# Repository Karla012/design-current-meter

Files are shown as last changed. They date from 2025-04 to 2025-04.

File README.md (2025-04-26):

# Diseño de un Sistema de Medición de Corriente para Microcontroladores con Transmisión Inalámbrica

### Autores
- **Karla Vanessa Ruíz González** — Universidad Industrial de Santander  
- **Óscar Andrés Meza Ortiz** — Universidad Industrial de Santander  

---

## Descripción del Proyecto

Este proyecto tiene como objetivo el diseño de un sistema electrónico operado por batería, que permita medir la corriente de operación de un microcontrolador en sus distintos modos de funcionamiento: modo normal y modo de sueño profundo. La medición se realiza de forma periódica, alternando entre ambos modos, lo que permite analizar el comportamiento energético del microcontrolador a lo largo del tiempo.

El sistema está diseñado para ofrecer precisión y bajo burden voltage en la medición, permitiendo detectar corrientes tanto en el orden de los miliamperios como de los microamperios. Para ello, se implementa un sistema de cambio de rango (manual o automático) que adapta la medición al nivel de corriente detectado. La señal medida es amplificada y enviada a un conversor analógico-digital, y finalmente, los datos se transmiten inalámbricamente a través de un microcontrolador ESP32.

---

## Estructura del Repositorio

- `docs/` – Informe final y presentación del proyecto.
- `hardware/` – Esquemáticos y diseño de PCB del circuito.
- `firmware/` – Código del microcontrolador para la transmisión inalámbrica.
- `simulacion/` – Resultados y archivos de simulaciones.
- `app_inventor/` – Archivos del diseño de la app móvil para visualizar los datos.

---

## Transmisión de Datos

El sistema emplea un ESP32 para la transmisión inalámbrica de las mediciones. Estas son recibidas por una aplicación desarrollada en [App Inventor](https://appinventor.mit.edu/), permitiendo visualizar en tiempo real el comportamiento de la corriente en el microcontrolador evaluado.

---

## Estado del Proyecto

Este trabajo corresponde al diseño completo y simulado del sistema de medición. No se realizó una implementación física, pero se desarrollaron y documentaron todos los bloques funcionales, respaldados por simulaciones, selección de componentes y diseño de una aplicación móvil funcional.

---

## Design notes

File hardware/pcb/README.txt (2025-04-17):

Contiene los archivos del diseño de la PCB para fabricación.

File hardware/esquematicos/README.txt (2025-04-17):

Contiene los esquemáticos del circuito de medición de corriente.

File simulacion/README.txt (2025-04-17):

Contiene resultados de simulaciones del sistema de medición.

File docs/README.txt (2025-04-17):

Contiene el informe y la presentación final del proyecto.

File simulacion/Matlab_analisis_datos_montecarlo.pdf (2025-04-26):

% Cargar los datos del archivo
fileID = fopen('Datos_montecarlo.txt', 'r');

% Inicializar un arreglo para almacenar los valores de V(n005) V = [];

% Leer el archivo línea por línea
tline = fgetl(fileID);
while ischar(tline)
% Verificar si la línea contiene un valor de V(n005) (con formato numérico)
if ~isempty(regexp(tline, '^[+-]?\d*\.?\d+', 'once'))
% Extraer el valor de V(n005) de la línea
values = sscanf(tline, '%e');
V = [V; values(2)]; % Solo tomar el segundo valor (V(n005)) end
tline = fgetl(fileID);
end

% Cerrar el archivo
fclose(fileID);

% Verificar los primeros valores extraídos disp('Primeros 10 valores de Vout:');

Primeros 10 valores de Vout:

disp(V(1:10));

1.0016
1.0016
1.0016
0.9843
0.9843
0.9843
1.0009
1.0009
1.0009
0.9948

% Simulación de Monte Carlo
num_simulations = 1000; % Número de simulaciones simulated_values = zeros(num_simulations, length(V));

% Realizar las simulaciones con variabilidad aleatoria
for i = 1:num_simulations
% Agregar ruido aleatorio a los valores de V
noise = 0.01 * randn(size(V)); % Generar ruido aleatorio simulated_values(i, :) = V + noise; % Simular con ruido añadido end

% Graficar el histograma de la distribución de los valores simulados

figure;
histogram(simulated_values(:), 20, 'Normalization', 'pdf', 'FaceColor', 'b'); % Histograma con 50 bins
hold on;

% Ajuste de una distribución normal a los datos simulados
mu = mean(simulated_values(:)); % Media de los datos simulados
sigma = std(simulated_values(:)); % Desviación estándar de los datos simulados
x = linspace(min(simulated_values(:)), max(simulated_values(:)), 100); % Rango para la función de densidad
y = normpdf(x, mu, sigma); % Calcular la función de densidad de probabilidad normal

% Graficar la línea roja
plot(x, y, 'r', 'LineWidth', 2); % Línea roja para la PDF ajustada

xlabel('Vout');
ylabel('Probability');
title('Monte Carlo y Ajuste normal (10 Ω)');
hold off;

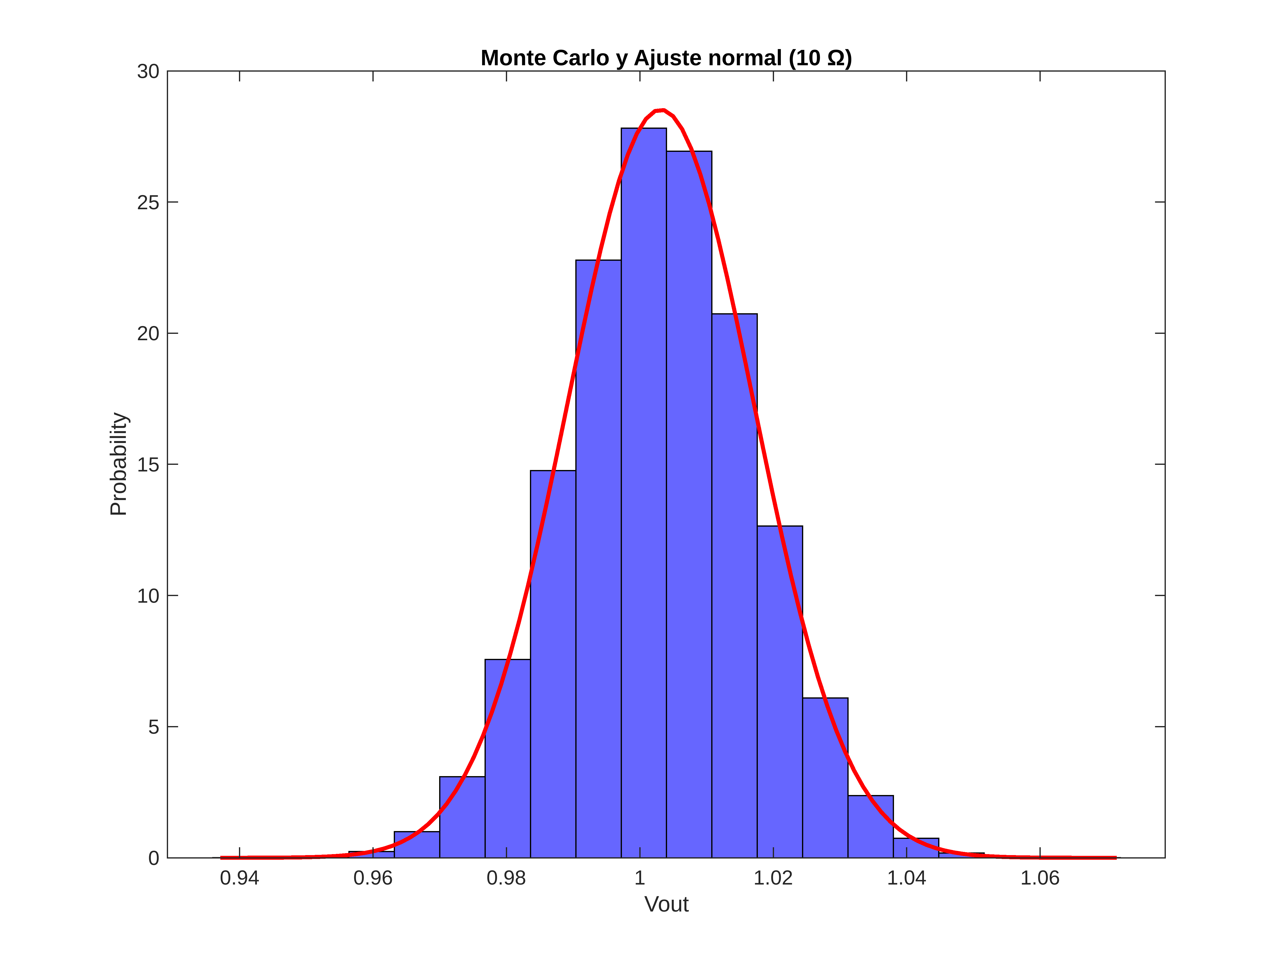
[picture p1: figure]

Montecarlo para resistencia de 0.01 Ω

% Cargar los datos del archivo
fileID = fopen('Datos_montecarlo0_01.txt', 'r');

% Inicializar un arreglo para almacenar los valores de V(n005) V = [];

% Leer el archivo línea por línea
tline = fgetl(fileID);
while ischar(tline)
% Verificar si la línea contiene un valor de V(n005) (con formato numérico)
if ~isempty(regexp(tline, '^[+-]?\d*\.?\d+', 'once'))
% Extraer el valor de V(n005) de la línea
values = sscanf(tline, '%e');
V = [V; values(2)]; % Solo tomar el segundo valor (V(n005)) end
tline = fgetl(fileID);
end

% Cerrar el archivo
fclose(fileID);

% Verificar los primeros valores extraídos disp('Primeros 10 valores de Vout:');

Primeros 10 valores de Vout:

disp(V(1:10));

1.0016
1.0016
1.0016
0.9843
0.9843
0.9843
1.0009
1.0009
1.0009
0.9948

% Simulación de Monte Carlo
num_simulations = 1000; % Número de simulaciones simulated_values = zeros(num_simulations, length(V));

% Realizar las simulaciones con variabilidad aleatoria
for i = 1:num_simulations
% Agregar ruido aleatorio a los valores de V
noise = 0.01 * randn(size(V)); % Generar ruido aleatorio simulated_values(i, :) = V + noise; % Simular con ruido añadido end

% Graficar el histograma de la distribución de los valores simulados

figure;
histogram(simulated_values(:), 20, 'Normalization', 'pdf', 'FaceColor', 'b'); % Histograma con 50 bins
hold on;

% Ajuste de una distribución normal a los datos simulados
mu = mean(simulated_values(:)); % Media de los datos simulados
sigma = std(simulated_values(:)); % Desviación estándar de los datos simulados
x = linspace(min(simulated_values(:)), max(simulated_values(:)), 100); % Rango para la función de densidad
y = normpdf(x, mu, sigma); % Calcular la función de densidad de probabilidad normal

% Graficar la línea roja
plot(x, y, 'r', 'LineWidth', 2); % Línea roja para la PDF ajustada

xlabel('Vout');
ylabel('Probability');
title('Monte Carlo y Ajuste normal (0.01 Ω)');
hold off;

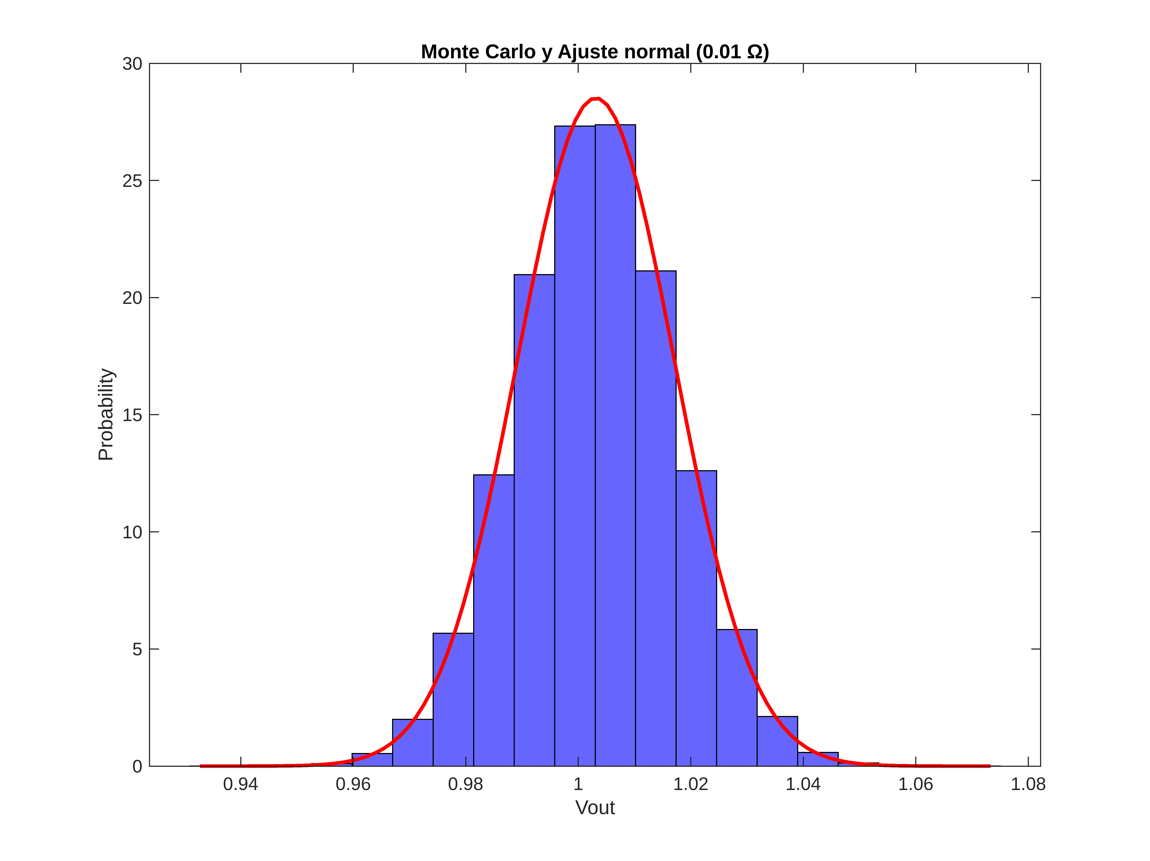
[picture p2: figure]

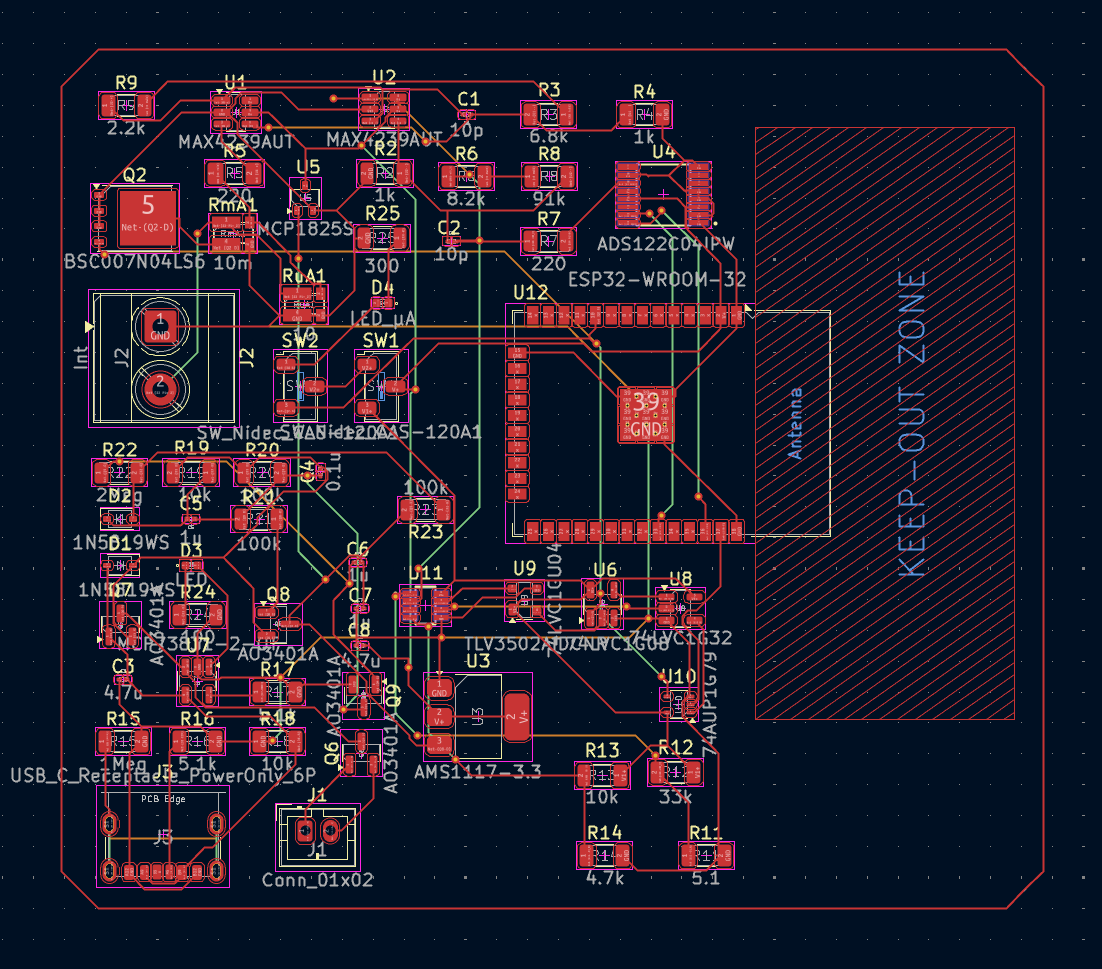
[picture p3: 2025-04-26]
hardware/pcb/Layout.png

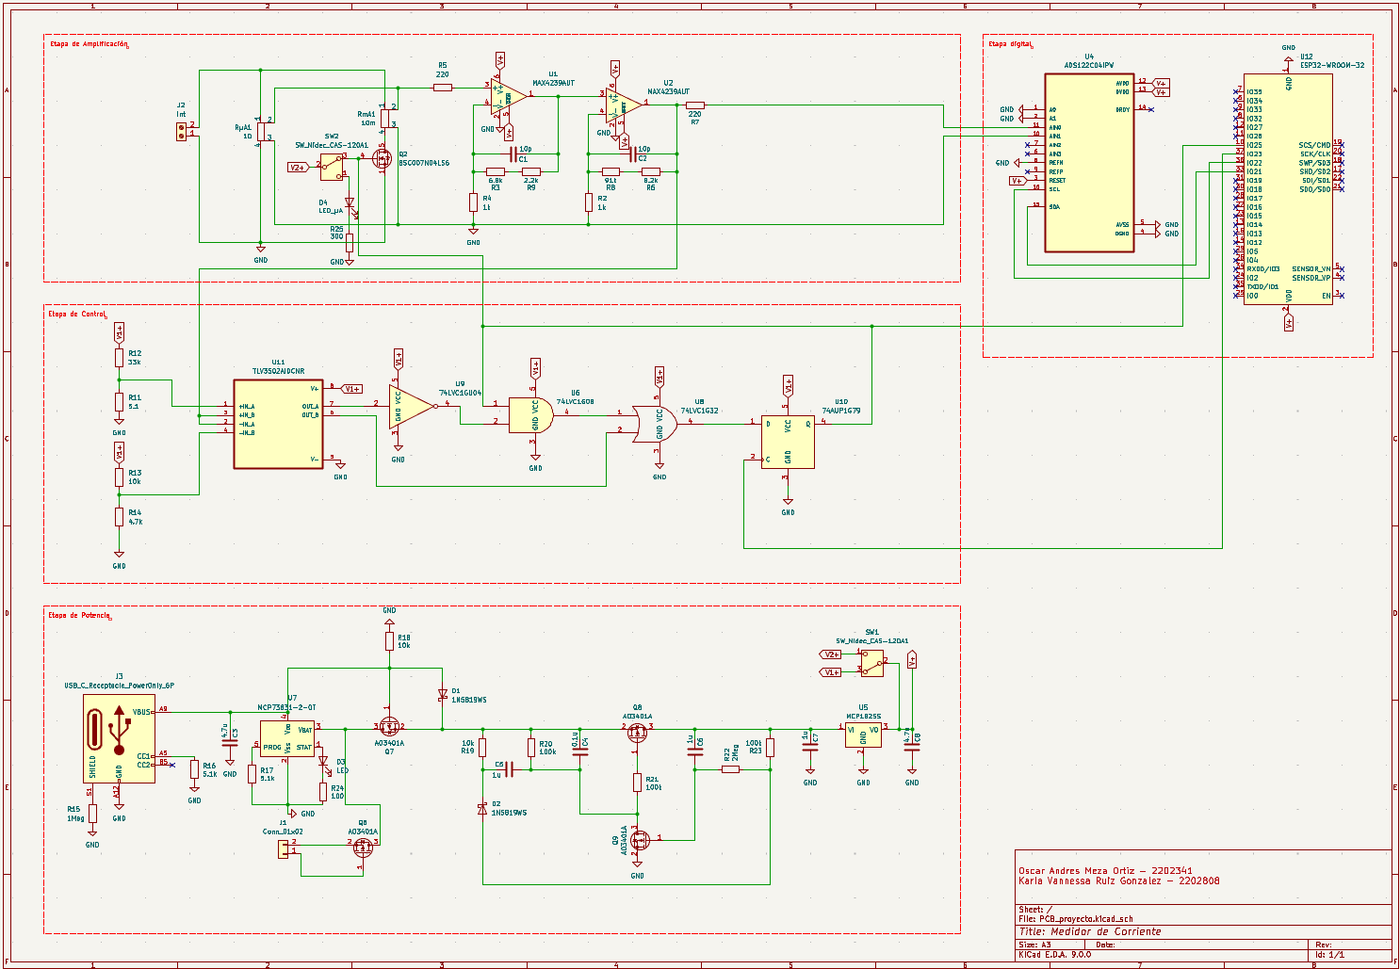
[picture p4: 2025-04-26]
hardware/esquematicos/Esquema_general.png

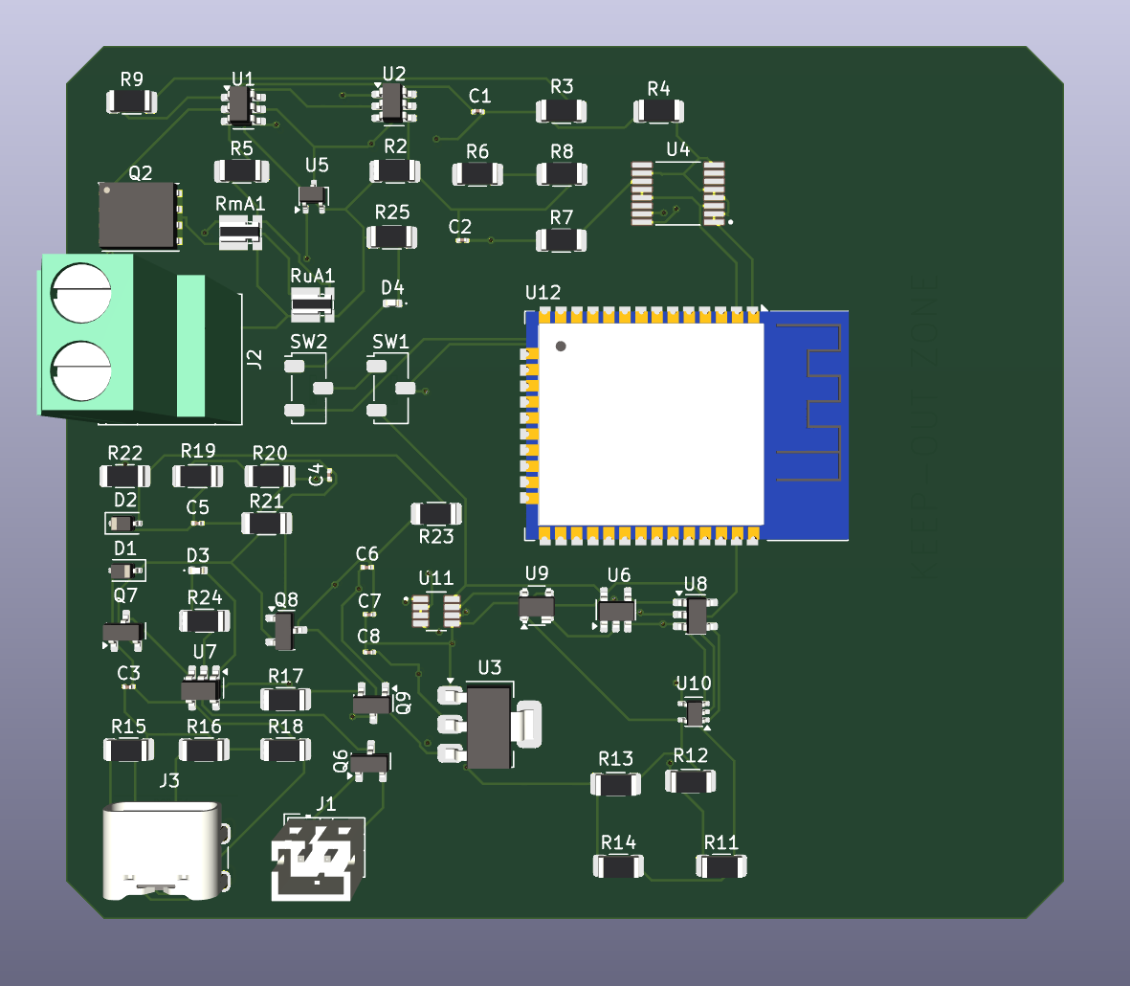
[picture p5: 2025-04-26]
hardware/pcb/PCB.png

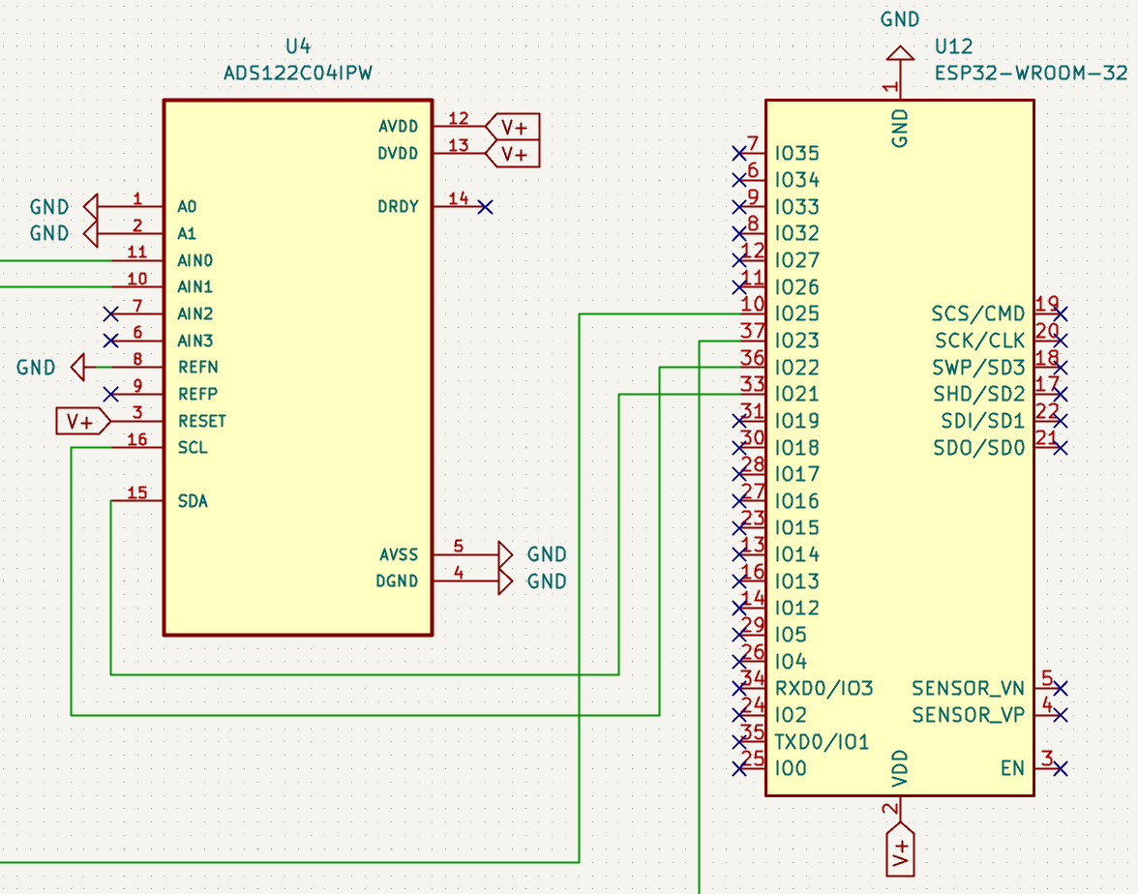
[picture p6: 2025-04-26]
hardware/esquematicos/E_Digital.png

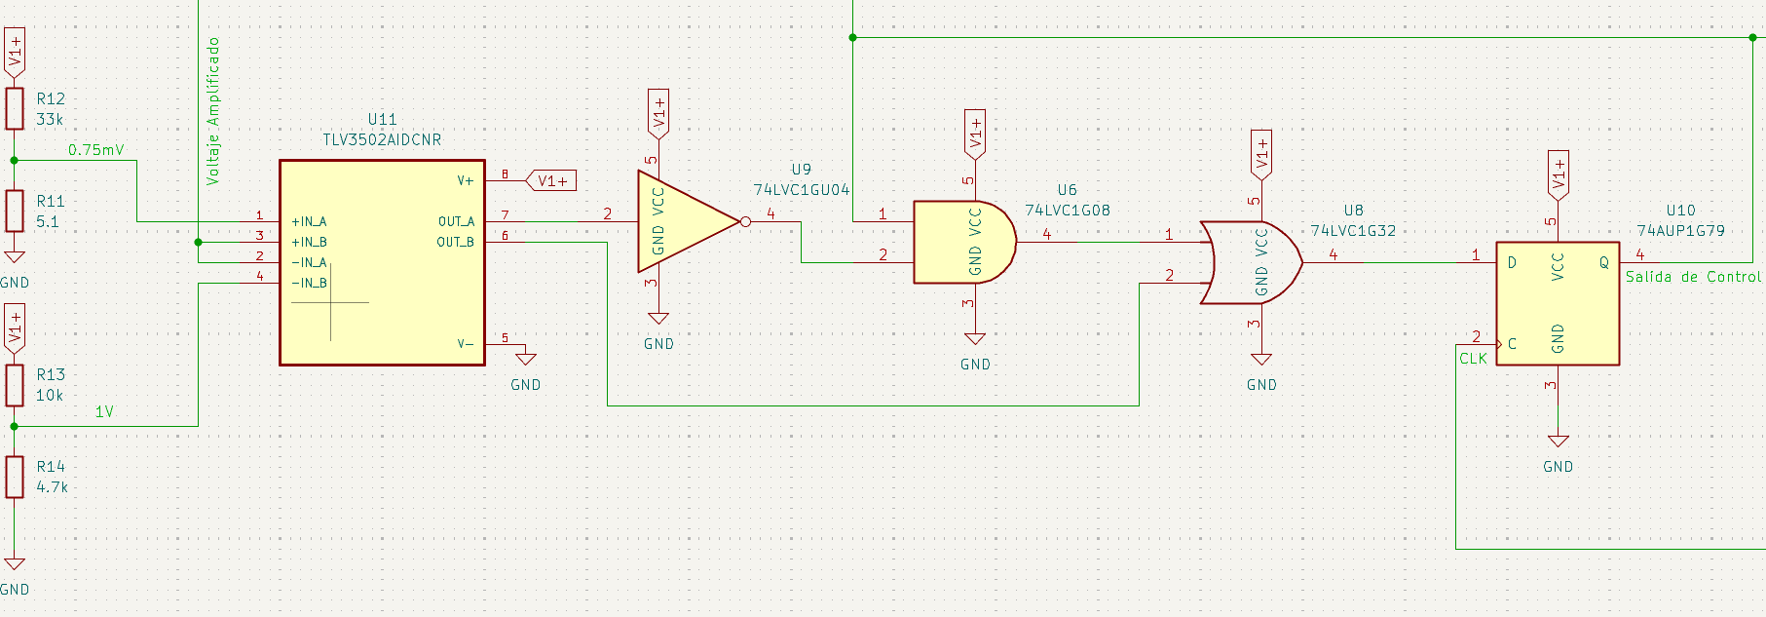
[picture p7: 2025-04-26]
hardware/esquematicos/E_control.png

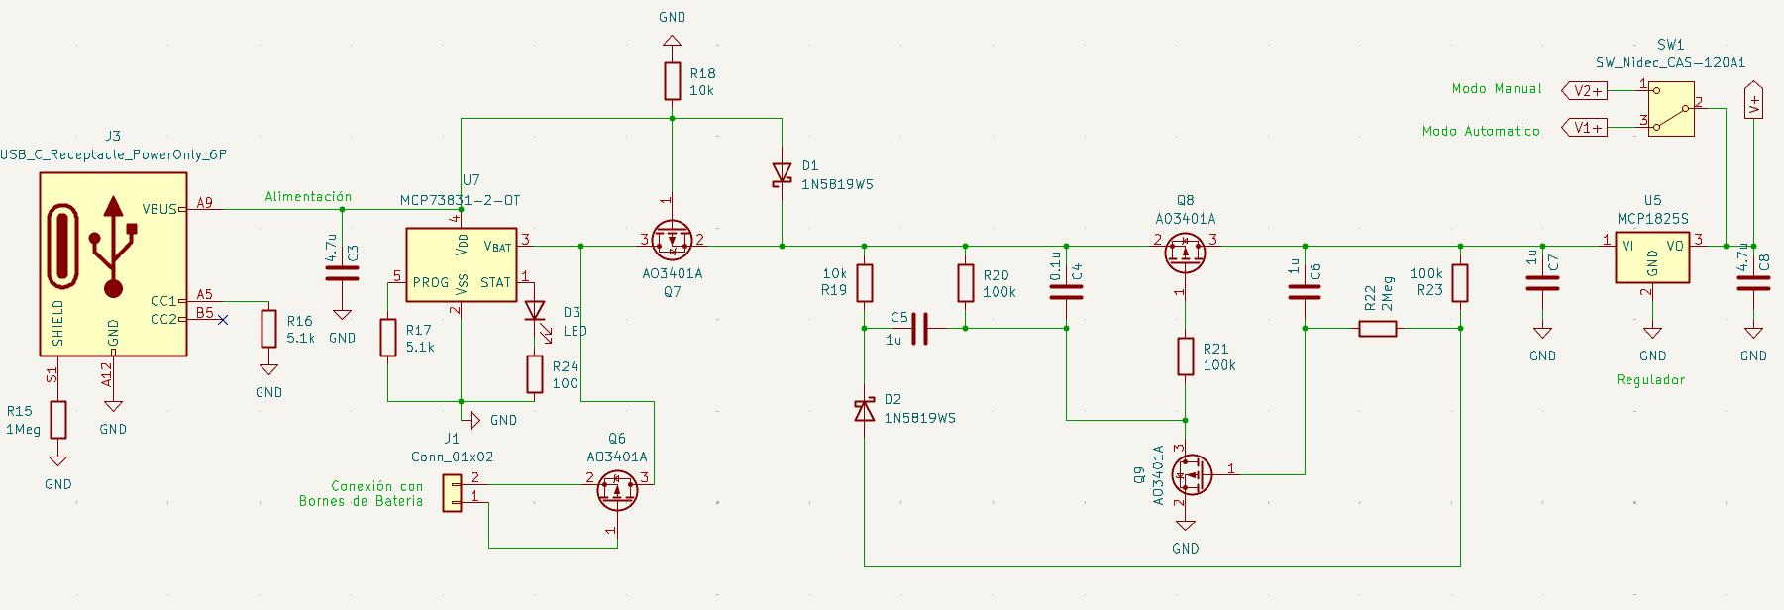
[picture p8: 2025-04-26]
hardware/esquematicos/Etapa_de_Potencia.png

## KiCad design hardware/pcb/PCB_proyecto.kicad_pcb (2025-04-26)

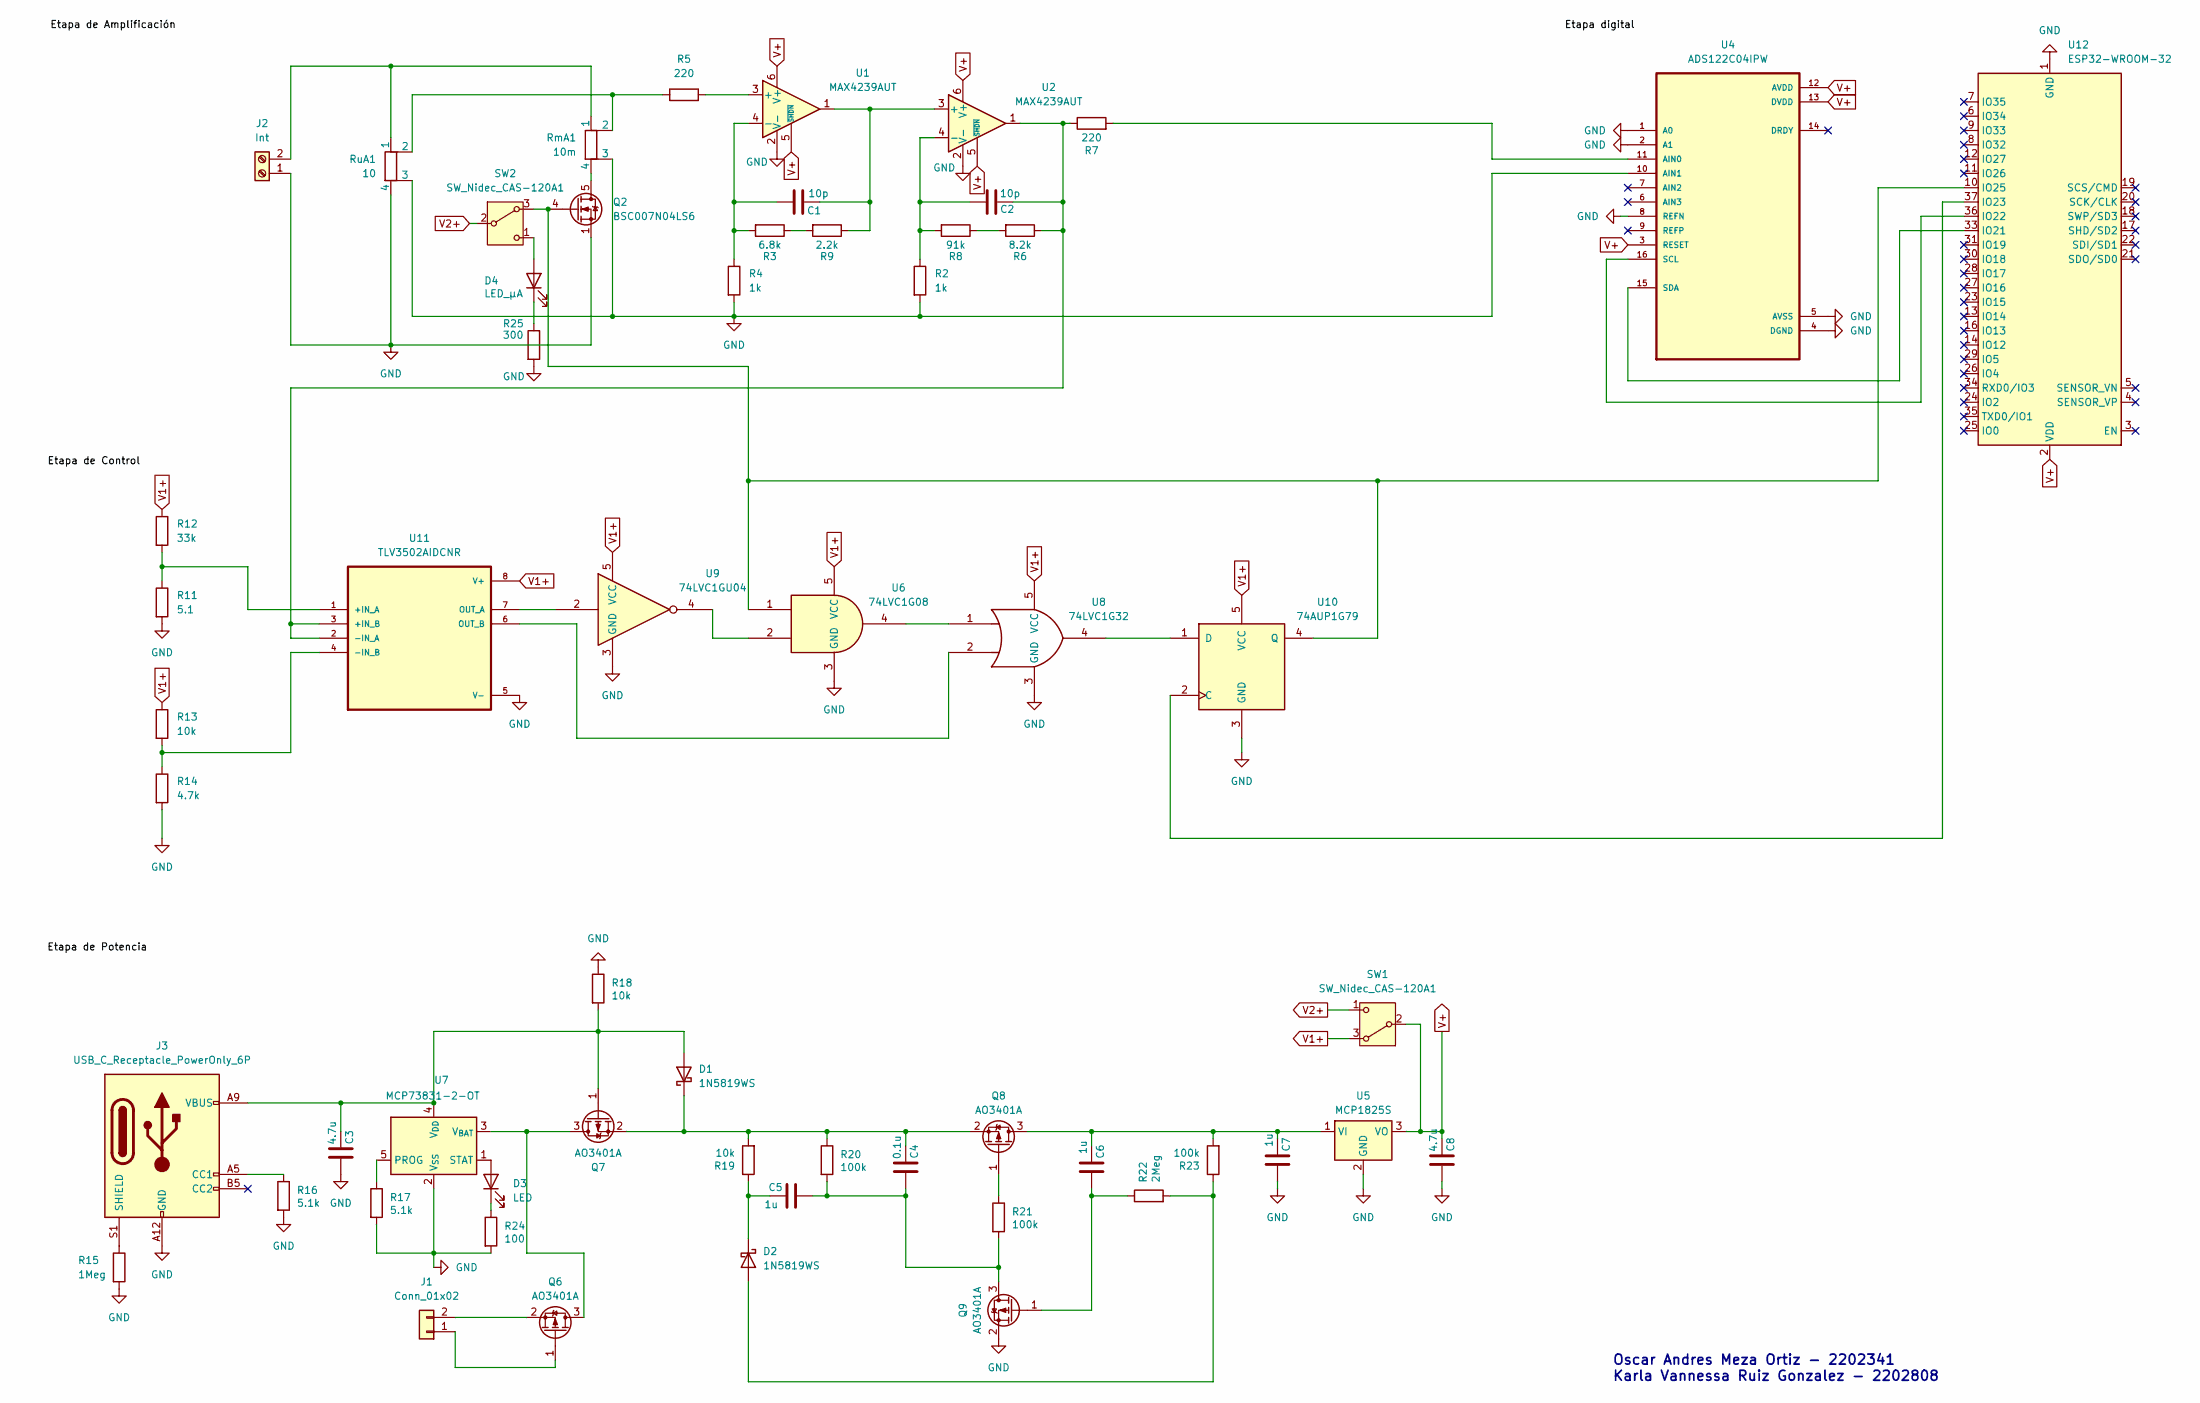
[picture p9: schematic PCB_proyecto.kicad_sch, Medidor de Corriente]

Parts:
C1, C2: 10p; C_0201_0603Metric
C3, C8: 4.7u; C_0201_0603Metric
C4: 0.1u; C_0201_0603Metric
C5, C6, C7: 1u; C_0201_0603Metric
D1, D2: 1N5819WS; D_SOD-323
D3: LED; LED_0402_1005Metric
D4: LED_µA; LED_0402_1005Metric
J1: Conn_01x02; JST_PH_B2B-PH-K_1x02_P2.00mm_Vertical
J2: Int; TerminalBlock_Phoenix_MKDS-3-2-5.08_1x02_P5.08mm_Horizontal
J3: USB_C_Receptacle_PowerOnly_6P; USB_C_Receptacle_GCT_USB4125-xx-x-0190_6P_TopMnt_Horizontal
Q2: BSC007N04LS6; TDSON-8-1
Q6, Q7, Q8, Q9: AO3401A; SOT-23
R2, R4: 1k; R_1206_3216Metric
R3: 6.8k; R_1206_3216Metric
R5: 220; R_1206_3216Metric_Pad1.30x1.75mm_HandSolder
R6: 8.2k; R_1206_3216Metric
R7: 220; R_1206_3216Metric
R8: 91k; R_1206_3216Metric
R9: 2.2k; R_1206_3216Metric
R11: 5.1; R_1206_3216Metric
R12: 33k; R_1206_3216Metric
R13, R18, R19: 10k; R_1206_3216Metric
R14: 4.7k; R_1206_3216Metric
R15: 1Meg; R_1206_3216Metric
R16, R17: 5.1k; R_1206_3216Metric
R20, R21, R23: 100k; R_1206_3216Metric
R22: 2Meg; R_1206_3216Metric
R24: 100; R_1206_3216Metric
R25: 300; R_1206_3216Metric
RmA1: 10m; R_Shunt_Vishay_WSKW0612
RuA1: 10; R_Shunt_Vishay_WSKW0612
SW1, SW2: SW_Nidec_CAS-120A1; Nidec_Copal_CAS-120A
U1, U2: MAX4239AUT; SOT-23-6
U4: ADS122C04IPW; SOP65P640X120-16N
U5: MCP1825S; SOT-323_SC-70
U6: 74LVC1G08; SOT-23-5
U7: MCP73831-2-OT; SOT-23-5
U8: 74LVC1G32; SOT-23-5
U9: 74LVC1GU04; SOT-143R
U10: 74AUP1G79; SOT-353_SC-70-5
U11: TLV3502AIDCNR; SOT65P280X145-8N
U12: ESP32-WROOM-32

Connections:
GND: C3.1, C7.1, C8.1, J2.1, J3.A12 (GND), J3.B12 (GND), Q2.1 (S), Q2.2 (S), Q2.3 (S), Q9.2 (S), R2.2, R4.2, R11.2, R14.2, R15.2, R16.2, R17.2, R18.1, R24.2, R25.2, RmA1.3, RuA1.3, RuA1.4, U1.2 (V-), U2.2 (V-), U4.1 (A0), U4.2 (A1), U4.4 (DGND), U4.5 (AVSS), U4.8 (REFN), U4.10 (AIN1), U5.2 (GND), U6.3 (GND), U7.2 (V_{SS}), U8.3 (GND), U9.3 (GND), U10.3 (GND), U11.5 (V-), U12.1 (GND), U12.15 (GND), U12.38 (GND), U12.39 (GND); also elsewhere on the board
unnamed: C3.2, D1.2 (A), J3.A9 (VBUS), J3.B9 (VBUS), Q7.1 (G), R18.2, U7.4 (V_{DD})
unnamed: C4.2, D1.1 (K), Q7.2 (S), Q8.2 (S), R19.2, R20.1
unnamed: D2.2 (A), R22.2, R23.1
unnamed: C5.2, D2.1 (K), R19.1
unnamed: D3.2 (A), U7.1 (STAT)
unnamed: D3.1 (K), R24.1
unnamed: D4.2 (A), SW2.1 (C)
unnamed: D4.1 (K), R25.1
unnamed: J1.1, Q6.1 (G)
unnamed: J1.2, Q6.2 (S)
unnamed: J2.2, RmA1.1, RuA1.1
unnamed: J3.A5 (CC1), R16.1
unnamed: J3.S1 (SHIELD), R15.1
unnamed: Q2.5 (D), RmA1.4
unnamed: Q2.4 (G), SW2.3 (A), U6.1, U10.4 (Q), U12.10 (IO25)
unnamed: Q6.3 (D), Q7.3 (D), U7.3 (V_{BAT})
unnamed 17: C6.2, C7.2, Q8.3 (D), R23.2, U5.1 (VI); also elsewhere on the board
unnamed: Q8.1 (G), R21.1
unnamed: C4.1, C5.1, Q9.3 (D), R20.2, R21.2
unnamed: C6.1, Q9.1 (G), R22.1
unnamed: R3.1, R9.2
unnamed: R5.1, RmA1.2, RuA1.2
unnamed: R6.2, R8.1
unnamed: R5.2, U1.3 (+)
unnamed: C1.1, R3.2, R4.1, U1.4 (-)
unnamed: C1.2, R9.1, U1.1, U2.3 (+)
unnamed: C2.1, R2.1, R8.2, U2.4 (-)
unnamed: R7.2, U4.11 (AIN0)
unnamed: U6.2, U9.4
unnamed: U6.4, U8.1
unnamed: R17.1, U7.5 (PROG)
unnamed: U10.2 (C), U12.37 (IO23)
unnamed: U8.4, U10.1 (D)
unnamed: R11.1, R12.2, U11.1 (+IN_A)
unnamed: C2.2, R6.1, R7.1, U2.1, U11.2 (-IN_A), U11.3 (+IN_B)
unnamed: R13.2, R14.1, U11.4 (-IN_B)
unnamed: U9.2, U11.7 (OUT_A)
unnamed: U8.2, U11.6 (OUT_B)
unnamed: U4.15 (SDA), U12.33 (IO21)
unnamed: U4.16 (SCL), U12.36 (IO22)
V1+: R12.1, R13.1, SW1.3 (A), U6.5 (VCC), U8.5 (VCC), U9.1, U9.5 (VCC), U10.5 (VCC), U11.8 (V+)
V2+: SW1.1 (C), SW2.2 (B)
V+: C8.2, SW1.2 (B), U1.5 (~SHDN), U1.6 (V+), U2.5 (~SHDN), U2.6 (V+), U4.3 (RESET), U4.12 (AVDD), U4.13 (DVDD), U5.3 (VO), U12.2 (VDD); also elsewhere on the board

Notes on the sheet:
Oscar Andres Meza Ortiz - 2202341 Karla Vannessa Ruiz Gonzalez - 2202808

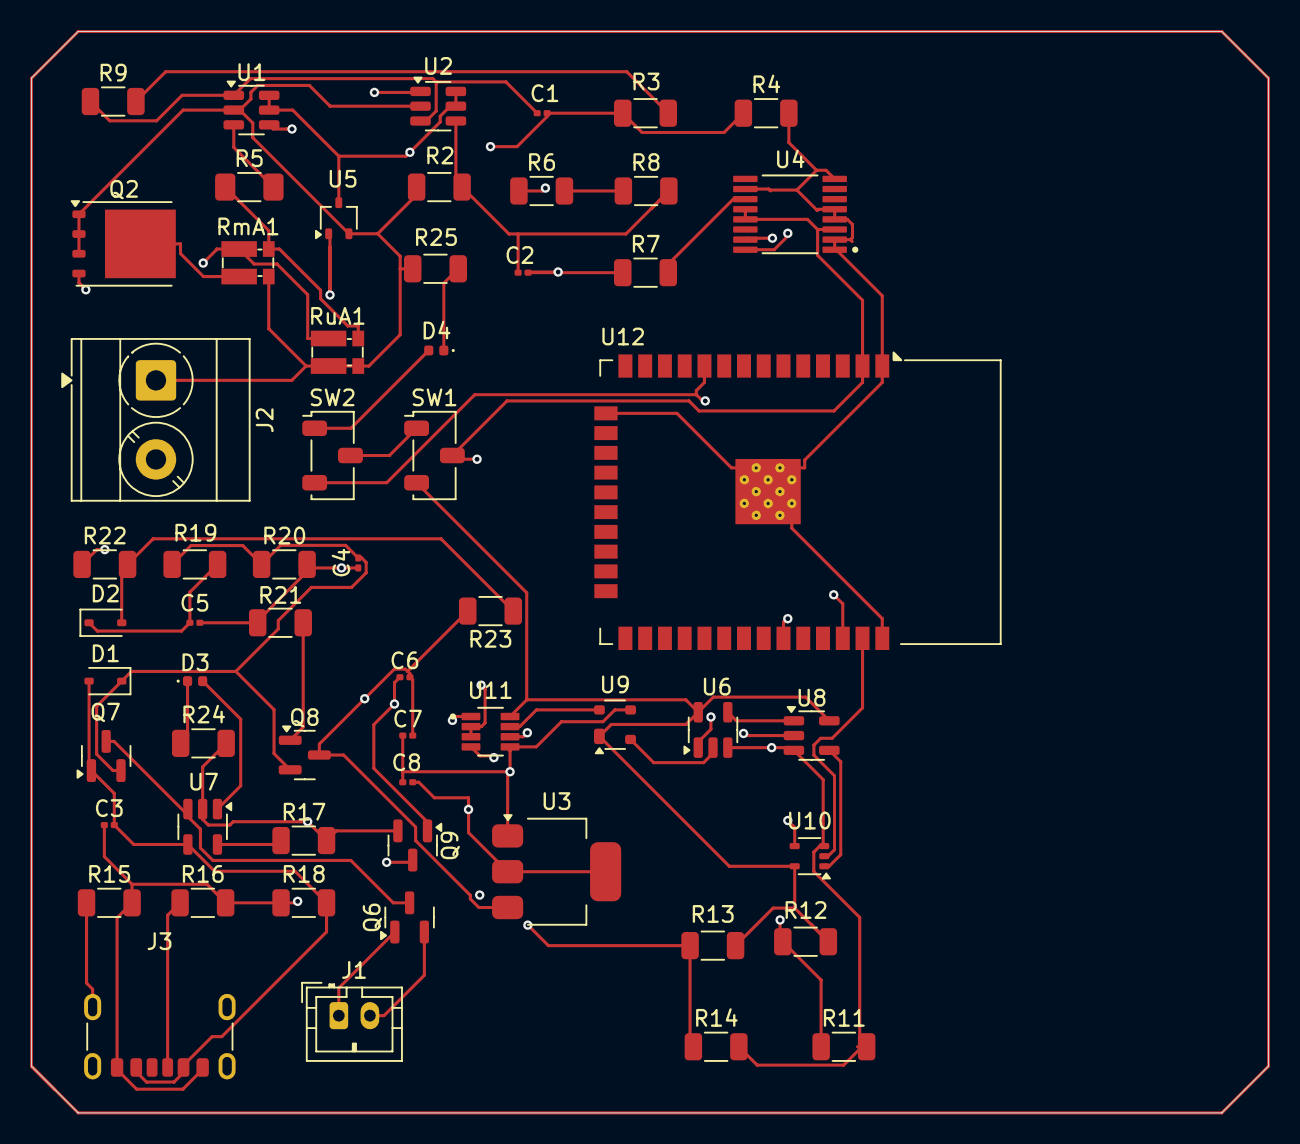
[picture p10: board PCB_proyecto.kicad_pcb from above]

Board: 4 copper layers, 79.5 x 69.5 mm, 59 parts (0 on the bottom side), 44 nets.

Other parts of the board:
U3: AMS1117-3.3; SOT-223-3_TabPin2

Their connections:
GND: U3.1 (GND); also elsewhere on the board
unnamed 17: U3.3 (VI); also elsewhere on the board
V+: U3.2 (VO); also elsewhere on the board

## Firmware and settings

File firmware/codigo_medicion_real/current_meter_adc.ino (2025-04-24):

#include <Wire.h>
#include <BluetoothSerial.h>
#include <SparkFun_ADS122C04_ADC_Arduino_Library.h>

BluetoothSerial SerialBT;
SFE_ADS122C04 adc;

#define CLK_PIN 23                     // Clock signal output pin
const int rangePin = 25;                   // Range selection pin
const float amplifierGain = 1000.0;        // Pre-ADC gain
unsigned long lastMillis = 0;
const unsigned long interval = 500;        // Reading interval in ms

void setup() {
  SerialBT.begin("CurrentMeter");         // Visible Bluetooth name
  Wire.begin();
  ledcSetup(0, 5000000, 8);      // Channel 0, 5 MHz, 8-bit resolution
  ledcAttachPin(CLK_PIN, 0);     // Attach the pin to the PWM channel
  ledcWrite(0, 128);             // Set 50% duty cycle (128 out of 256)


  pinMode(rangePin, INPUT);               // Configure pin as input for range selection

  if (!adc.begin()) {
    Serial.println("Error: ADC not detected.");
    while (1);
  }
  adc.configureADCmode(ADS122C04_RAW_MODE); // Configure ADC(auto mode, internal reference)
}

void loop() {
  if (millis() - lastMillis >= interval) {
    lastMillis = millis();

    bool highRange = digitalRead(rangePin);          // HIGH = 10 mΩ, LOW = 10 Ω
    float amplifiedVoltage = adc.readVoltage();      // Direct ADC reading in volts
    float shuntVoltage = amplifiedVoltage/amplifierGain;

    float current = 0.0;
    String unit;

    if (highRange) {
      current = shuntVoltage / 0.01;                // 10 mΩ → 0.01 Ω
      current *= 1000.0;                           // Convert A to mA
      unit = "mA";
    } else {
      current = shuntVoltage / 10.0;                // 10 Ω
      current *= 1000000.0;                         // Convert A to µA
      unit = "uA";
    }
    String message = String(current, 2) + " " + unit;
    SerialBT.println(message);
  }
}

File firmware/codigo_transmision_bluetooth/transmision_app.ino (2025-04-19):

#include <BluetoothSerial.h>

BluetoothSerial SerialBT;

unsigned long lastChange = 0;          // Last state change time
const unsigned long changeInterval = 10000; // 10-second interval
const unsigned long sendInterval = 500;     // 500 ms interval

bool currentHIGH = false;    // false = 10 µA, true = 80 mA
unsigned long lastSend = 0;  // Last data transmission time

void setup() {
  SerialBT.begin("CurrentMeter"); // Initialize Bluetooth with device name
}

void loop() {
  // Toggle currentHIGH state every 10 seconds
  if (millis() - lastChange >= changeInterval) {
    lastChange = millis();
    currentHIGH = !currentHIGH;  // Invert the state
  }

  // Send message every 500 ms
  if (millis() - lastSend >= sendInterval) {
    lastSend = millis();
    String message = currentHIGH ? "80.00 mA" : "10.00 µA";
    SerialBT.println(message);  // Transmit via Bluetooth
  }
}
